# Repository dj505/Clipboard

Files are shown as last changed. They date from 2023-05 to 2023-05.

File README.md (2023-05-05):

# Clipboard
A macropad made to make copy/paste easier  
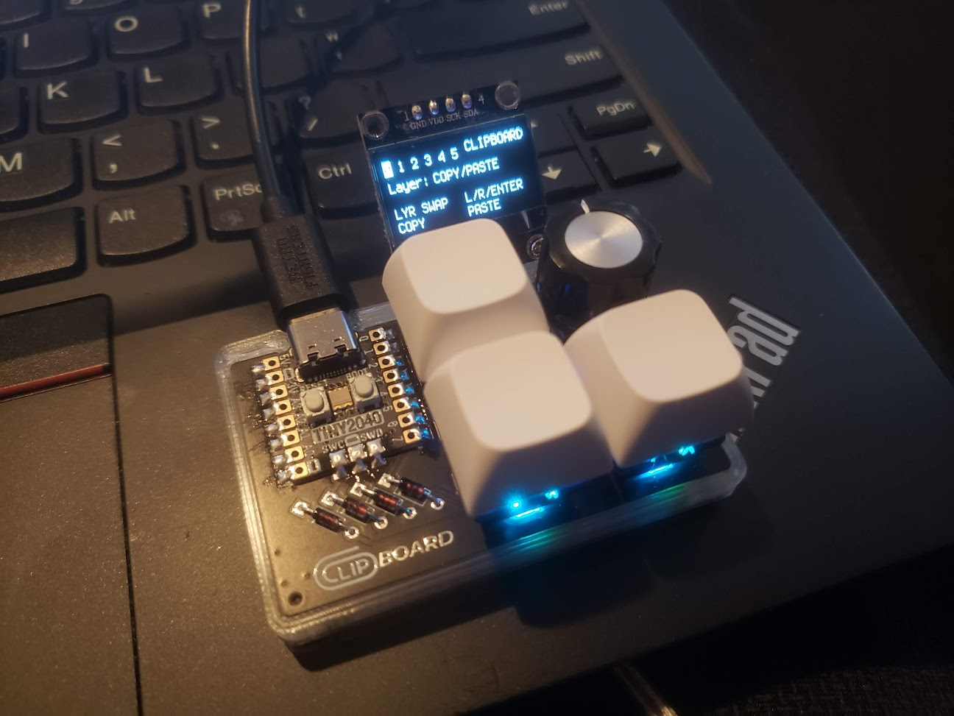
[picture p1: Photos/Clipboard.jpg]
Fully assembled Clipboard Clipboard


## Isn't this basically just a small macropad?
Yes! There's no reason you have to use this exclusively for copy/pasting, or other common shortcuts. You can do whatever you want with it, really. I was comissioned to design this by a friend who does a lot of copy/pasting at work. As he would like to save himself from a perpetually sore wrist, it was designed to the specifications he provided, right down to the specific intended use case. Since it's meant to be used for copying and pasting in an office-like environment, "Clipboard" just so happened to be a good play on words. (Shoutouts to clue for pointing that out!)

## Ok but what about the components?? The Tiny2040 is like $15 alone!
Short answer: Because I already have the parts lol

Long answer: To keep costs down, the deisgn was made to use parts we (myself and the friend who commissioned this board) already own. We both have a spare Tiny2040, I have hundreds of 1N4148 diodes from making keyboards, and I also have tons of leftover Kailh sockets and SK6812MINI-Es from the initial run of the [PicoLX](https://github.com/dj505/PicoLX).

## Update: [RP2040-Zero branch available here!](https://github.com/dj505/clipboard/tree/rp2040-zero)
The RP2040 Zero is significantly cheaper and has a near-identical pinout. Some pins remain unused but you can solder straight to the pins if you want to add any extra peripherals.

# Bill of Materials

| Part | Package | Qty |
|---|---|-----|
| 100nF Capacitor  | 0805 | 3 |
| 1N4148 Diode | DO-35 | 4 |
| SK6812MINI-E | MINI-E | 3 |
| Keyboard Switch  | MX-style | 3 |
| Rotary Encoder | PEC12R-4215F-S0024| 1 |
| Pimoroni Tiny2040| N/A | 1 |
| SN74LV1T34DBV | SOT-23-5 | 1 |

# Firmware
This board was developed using [KMK Firmware](https://github.com/KMKfw/kmk_firmware). Instructions for setting up KMK on your board can be found in the [Getting Started](https://github.com/KMKfw/kmk_firmware/blob/master/docs/en/Getting_Started.md) docs.

After KMK itself is set up, delete the existing `code.py` or `main.py` on the CIRCUITPY drive, and copy the `code.py` file in this repository's "keymap" directory to the root of the drive.

You're done!

## Notes on the firmware
- By default, it does a lot. Maybe too much. *Probably* too much, actually. Please feel free to edit it down for your own use case! The [KMK docs](http://kmkfw.io/docs/) are your friend.
- The OLED code used here is currently undocumented. It's fully reworked from example code I found on a GitHub issue thread that I can't seem to find again. It should be straightforward enough to understand, though!

## Required CircuitPython libraries
CircuitPython libraries can be found [here.](https://circuitpython.org/libraries)  
This project will require the following libraries from the "lib" folder of the library bundle:
* neopixel.mpy
* adafruit_displayio_ssd1306.mpy (required for OLED)
* adafruit_display_text (required for OLED)  
Copy these files and folders into the "lib" folder on your CIRCUITPY drive.

## Connecting an OLED display
Clipboard is made with an I2C 128x64 SSD1306 OLED display in mind. If you have a different display with a different resolution, you will have to edit `code.py` accordingly. The underside of the board has the appropriate pins marked, with **SDA on GP26** and **SCL on GP27**. The VCC (or VDD (or 3.3V)) pin on the OLED should be wired to the +3V3 pin on the Clipboard.

# Credits
* [Tiny2040 Symbol & Footprint](https://github.com/chinatsu/tiny2040) by [chinatsu](https://github.com/chinatsu) - Licensed under Creative Commons Attribution-ShareAlike 3.0 Unported. License can be found in `rp2040` directory. The following changes were made to the pcbnew footprint for this project:
    * "U1" and "Tiny2040" text on silkscreen layer have been moved
    * Rectangular pads were added to the front copper layer to allow for surface mounting
    * Silkscreen outline was changed so as to not overlap with the rectangular pads
* [marbastlib](https://github.com/ebastler/marbastlib) by [ebastler](https://github.com/ebastler) - Licensed under the CERN Open Hardware Licence Version 2 - Permissive.
* [MX_V2](https://github.com/ai03-2725/MX_V2) and [MX_Alps_Hybrid](https://github.com/ai03-2725/MX_Alps_Hybrid) by [ai03](https://github.com/ai03-2725) - Both licensed under the MIT License.

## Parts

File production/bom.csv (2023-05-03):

Designator | Footprint | Quantity | Value | LCSC Part #
C1, C2, C3 | 0805 | 3 | 100nF | C1525
D1, D2, D3, D4 | D_DO-35_SOD27_P7.62mm_Horizontal | 4 | 1N4148
J1 | PinHeader_1x08_P2.54mm_Vertical | 1 | Conn_01x08
LED1, LED2, LED3 | LED_MX_6028R | 3 | SK6812MINI-E
MX1, MX2, MX3 | MX-Hotswap-1U | 3 | MX-NoLED
SW1 | RotaryEncoder_Bourns_Vertical_PEC12R-3xxxF-Sxxxx | 1 | PEC12R-4215F-S0024
U1 | tiny2040 | 1 | tiny2040
U2 | SOT-23-5 | 1 | SN74LV1T34DBV | C100024

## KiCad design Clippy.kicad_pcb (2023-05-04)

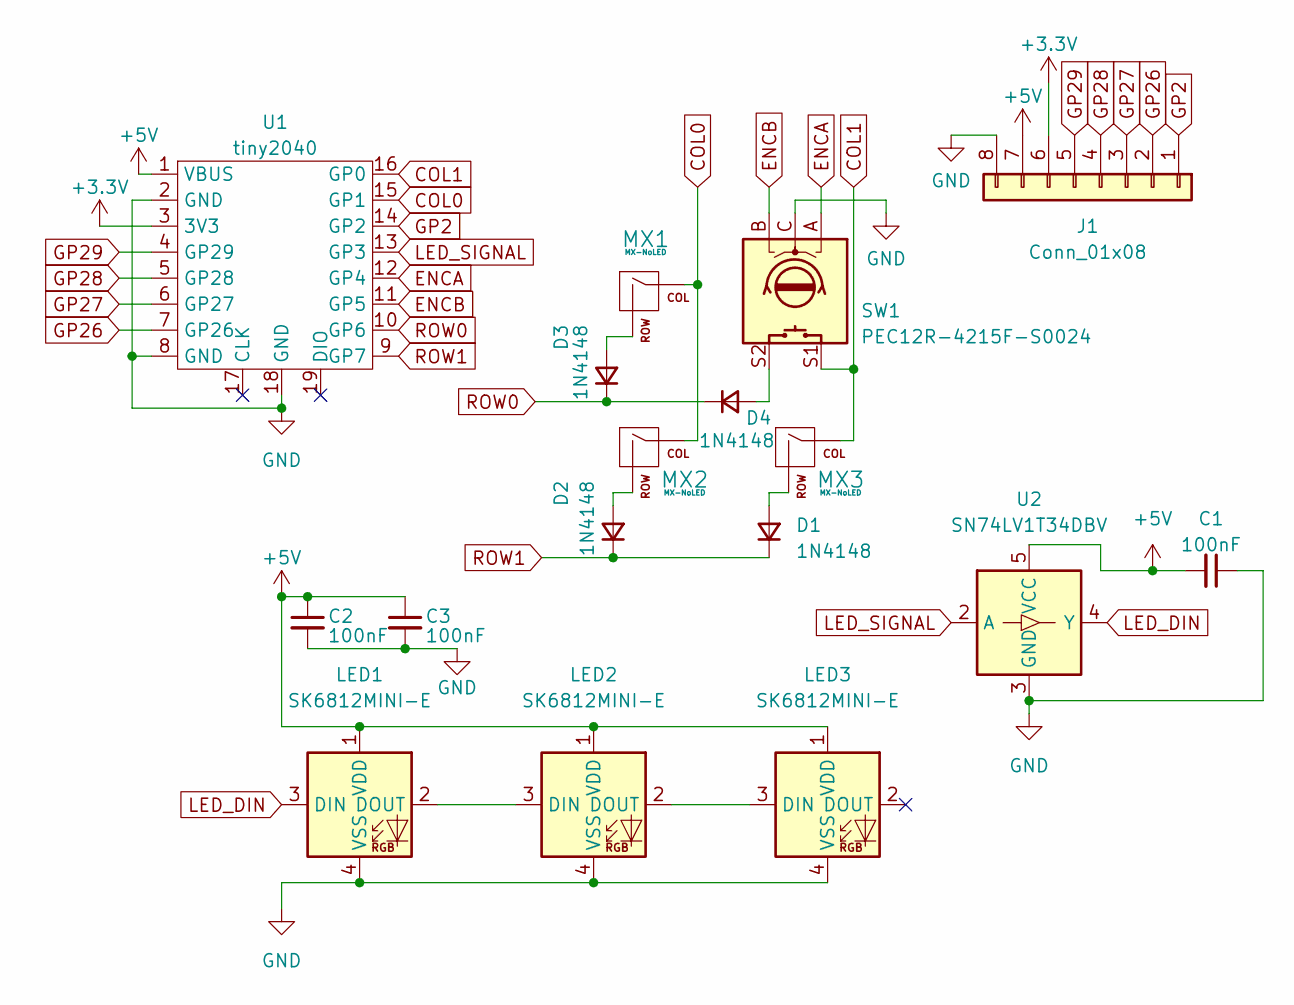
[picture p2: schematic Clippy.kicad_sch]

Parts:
C1, C2, C3: 100nF; C_0805_2012Metric_Pad1.18x1.45mm_HandSolder; LCSC C1525
D1, D2, D3, D4: 1N4148; D_DO-35_SOD27_P7.62mm_Horizontal
J1: Conn_01x08; PinHeader_1x08_P2.54mm_Vertical
LED1, LED2, LED3: SK6812MINI-E; LED_MX_6028R
MX1, MX2, MX3: MX-NoLED; MX-Hotswap-1U
SW1: PEC12R-4215F-S0024; RotaryEncoder_Bourns_Vertical_PEC12R-3xxxF-Sxxxx
U1: tiny2040
U2: SN74LV1T34DBV; SOT-23-5; LCSC C100024

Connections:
+3.3V: J1.6, U1.3 (3V3)
+5V: C1.2, C2.1, C3.1, J1.7, LED1.1 (VDD), LED2.1 (VDD), LED3.1 (VDD), U1.1 (VBUS), U2.5 (VCC)
COL0: MX1.1 (COL), MX2.1 (COL), U1.15 (GP1)
COL1: MX3.1 (COL), SW1.S1, U1.16 (GP0)
ENC0: SW1.A, U1.12 (GP4)
ENC1: SW1.B, U1.11 (GP5)
GND: C1.1, C2.2, C3.2, J1.8, LED1.4 (VSS), LED2.4 (VSS), LED3.4 (VSS), SW1.C, U1.2 (GND), U1.8 (GND), U1.18 (GND), U2.3 (GND)
GP2: J1.1, U1.14 (GP2)
GP26: J1.2, U1.7 (GP26)
GP27: J1.3, U1.6 (GP27)
GP28: J1.4, U1.5 (GP28)
GP29: J1.5, U1.4 (GP29)
LED_DIN: LED1.3 (DIN), U2.4 (Y)
LED_SIGNAL: U1.13 (GP3), U2.2 (A)
unnamed: D1.2 (A), MX3.2 (ROW)
unnamed: D2.2 (A), MX2.2 (ROW)
unnamed: D3.2 (A), MX1.2 (ROW)
unnamed: D4.2 (A), SW1.S2
unnamed: LED1.2 (DOUT), LED2.3 (DIN)
unnamed: LED2.2 (DOUT), LED3.3 (DIN)
ROW0: D3.1 (K), D4.1 (K), U1.10 (GP6)
ROW1: D1.1 (K), D2.1 (K), U1.9 (GP7)

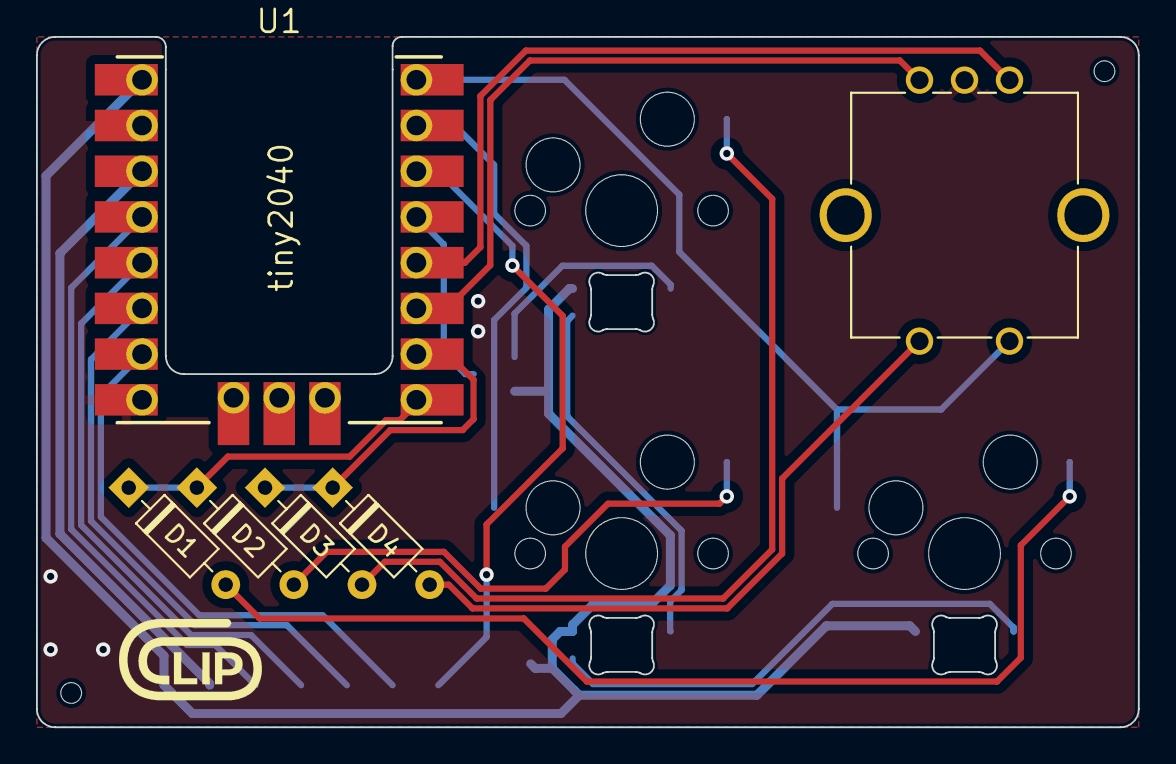
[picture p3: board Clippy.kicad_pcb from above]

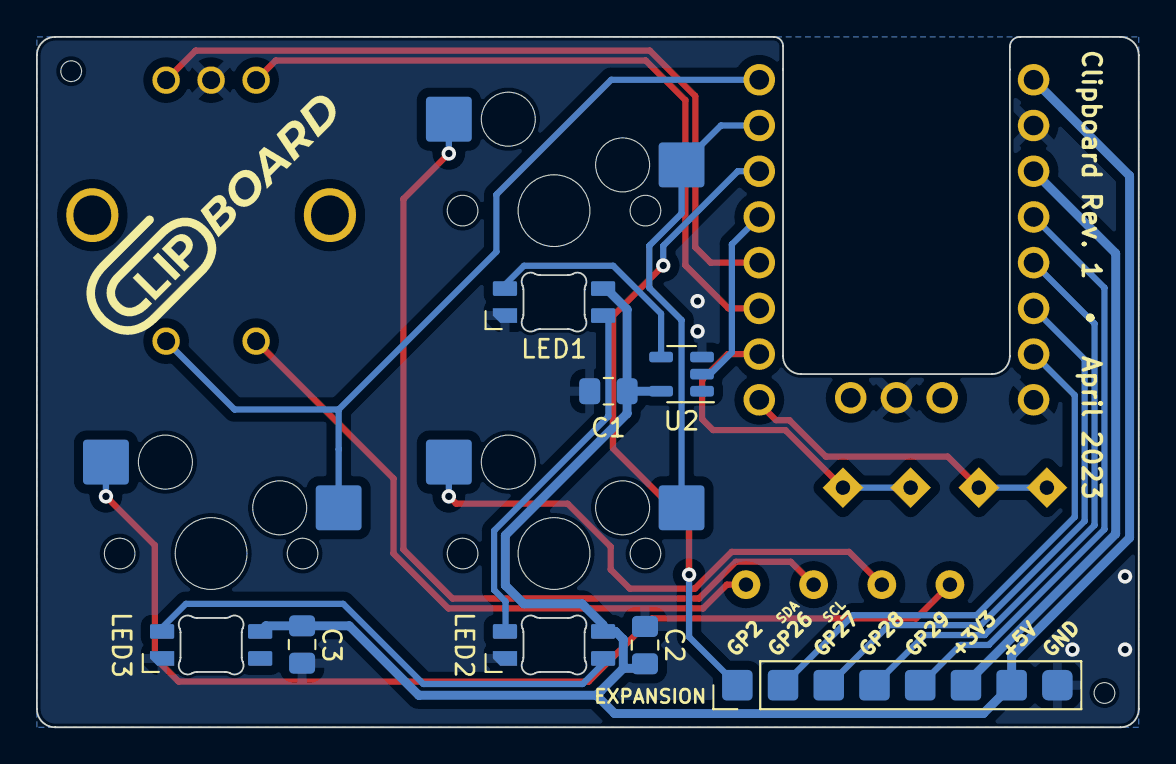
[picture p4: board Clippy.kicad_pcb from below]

Board: 2 copper layers, 61.2 x 38.4 mm, 17 parts (8 on the bottom side), 22 nets.

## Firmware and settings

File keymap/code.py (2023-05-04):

import board
import busio

from kmk.kmk_keyboard import KMKKeyboard
from kmk.keys import KC
from kmk.handlers.sequences import simple_key_sequence
from kmk.scanners import DiodeOrientation
from kmk.modules.layers import Layers
from kmk.modules.tapdance import TapDance
from kmk.modules.encoder import EncoderHandler
from kmk.modules.power import Power
from kmk.extensions.media_keys import MediaKeys
from kmk.extensions.RGB import RGB, AnimationModes
from kmk.extensions.LED import LED
from kmk.extensions.lock_status import LockStatus
from kmk.extensions.oled import (
    Oled,
    TextEntry,
    ImageEntry
)

keyboard = KMKKeyboard()

# Custom "Keys"
PAINT = simple_key_sequence(
    (
        KC.LGUI(KC.R),
        KC.MACRO_SLEEP_MS(500),
        KC.M,
        KC.S,
        KC.P,
        KC.A,
        KC.I,
        KC.N,
        KC.T,
        KC.ENTER
    )
)
TASKMGR = KC.LCTRL(KC.LSHIFT(KC.ESC))
LOCK = KC.LGUI(KC.L)

tapdance = TapDance()
tapdance.tap_time = 250
keyboard.modules.append(tapdance)

power = Power()
keyboard.modules.append(power)

i2c_bus = busio.I2C(board.GP27, board.GP26)

oled_ext = Oled(
    entries=[
        TextEntry(text='CLIPBOARD', x=128, y=0, x_anchor='R'),
        TextEntry(text='Layer: ', x=0, y=32, y_anchor='B'),
        TextEntry(text='COPY/PASTE', x=40, y=32, y_anchor='B', layer=0),
        TextEntry(text='UNDO/REDO', x=40, y=32, y_anchor='B', layer=1),
        TextEntry(text='SCREENSHOT', x=40, y=32, y_anchor='B', layer=2),
        TextEntry(text='MISC SYSTEM', x=40, y=32, y_anchor='B', layer=3),
        TextEntry(text='MEDIA', x=40, y=32, y_anchor='B', layer=4),
        TextEntry(text='RGB', x=40, y=32, y_anchor='B', layer=5),
        TextEntry(text='SETTINGS', x=40, y=32, y_anchor='B', layer=6),
        TextEntry(text='0123456', x=0, y=4),
        TextEntry(text='0', x=0, y=4, inverted=True, layer=0),
        TextEntry(text='1', x=6, y=4, inverted=True, layer=1),
        TextEntry(text='2', x=12, y=4, inverted=True, layer=2),
        TextEntry(text='3', x=18, y=4, inverted=True, layer=3),
        TextEntry(text='4', x=24, y=4, inverted=True, layer=4),
        TextEntry(text='5', x=30, y=4, inverted=True, layer=5),
        TextEntry(text='6', x=36, y=4, inverted=True, layer=6),

        # Rotary encoder labels
        TextEntry(text='L/R', x=64, y=42, layer=0),
        TextEntry(text='VOLUME', x=64, y=42, layer=1),
        TextEntry(text='ZOOM', x=64, y=42, layer=2),
        TextEntry(text='PNT ZOOM', x=64, y=42, layer=3),
        TextEntry(text='VOLUME', x=64, y=42, layer=4),
        TextEntry(text='RGB HUE', x=64, y=42, layer=5),
        TextEntry(text='UNUSED', x=64, y=42, layer=6),

        # Key labels
        TextEntry(text='SELECT', x=0, y=42, layer=0),
        TextEntry(text='COPY', x=0, y=54, layer=0),
        TextEntry(text='PASTE', x=64, y=54, layer=0),
        TextEntry(text='MUTE', x=0, y=42, layer=1),
        TextEntry(text='UNDO', x=0, y=54, layer=1),
        TextEntry(text='REDO', x=64, y=54, layer=1),
        TextEntry(text='RST ZOOM', x=0, y=42, layer=2),
        TextEntry(text='ALT+PRTSC', x=0, y=54, layer=2),
        TextEntry(text='SNIP TOOL', x=64, y=54, layer=2),
        TextEntry(text='PAINT', x=0, y=42, layer=3),
        TextEntry(text='TASK MNGR', x=0, y=54, layer=3),
        TextEntry(text='LOCK SCRN', x=64, y=54, layer=3),
        TextEntry(text='PLAY/PAUSE', x=0, y=42, layer=4),
        TextEntry(text='PREV SONG', x=0, y=54, layer=4),
        TextEntry(text='NEXT SONG', x=64, y=54, layer=4),
        TextEntry(text='RGB TGL', x=0, y=42, layer=5),
        TextEntry(text='SPD-', x=0, y=54, layer=5),
        TextEntry(text='SPD+', x=64, y=54, layer=5),
        TextEntry(text='DEBUG TGL', x=0, y=42, layer=6),
        TextEntry(text='RESET', x=0, y=54, layer=6),
        TextEntry(text='RELOAD', x=64, y=54, layer=6),
    ],
    i2c=i2c_bus,
    device_address=0x3C,
    width=128,
    height=64,
    flip=False,
    flip_left=False,
    flip_right=True,
    dim_time=10,
    dim_target=0.1,
    off_time=120,
    powersave_dim_time=5,
    powersave_dim_target=0.1,
    powersave_off_time=15,
    brightness=1,
    brightness_step=0.1,
)
keyboard.extensions.append(oled_ext)

leds = LED(led_pin=[board.LED_R, board.LED_G, board.LED_B])
# Num lock = red
# Caps lock = green
# Scroll lock = blue

class LEDLockStatus(LockStatus):
    def set_lock_leds(self):
        if not self.get_num_lock():
            leds.set_brightness(100, leds=[0])
        else:
            leds.set_brightness(0, leds=[0])

        if not self.get_caps_lock():
            leds.set_brightness(100, leds=[1])
        else:
            leds.set_brightness(0, leds=[1])

        if not self.get_scroll_lock():
            leds.set_brightness(100, leds=[2])
        else:
            leds.set_brightness(0, leds=[2])

    def after_hid_send(self, sandbox):
        super().after_hid_send(sandbox)
        if self.report_updated:
            self.set_lock_leds()

keyboard.extensions.append(leds)
keyboard.extensions.append(LEDLockStatus())

keyboard.col_pins = (board.GP1, board.GP0)
keyboard.row_pins = (board.GP6, board.GP7)
keyboard.diode_orientation = DiodeOrientation.COL2ROW

layers = Layers()
keyboard.modules.append(layers)

media_keys = MediaKeys()
keyboard.extensions.append(media_keys)

frontglow = RGB(
    pixel_pin=board.GP3,
    num_pixels=3,
    val_limit=100,
    val_default=25,
    animation_mode=AnimationModes.RAINBOW,
)
keyboard.extensions.append(frontglow)

keyboard.keymap = [
    [   # Layer 1 - Copy/Paste
        KC.TD(KC.LSHIFT, KC.LCTRL(KC.A)), KC.TD(KC.TO(1), KC.TO(6)), # Shift/Ctrl+A, Toggle layer 2,
        KC.LCTRL(KC.C),                   KC.LCTRL(KC.V)             # Ctrl+C, Ctrl+V
    ],
    [
        # Layer 2 - Undo/Redo
        KC.MUTE,                          KC.TD(KC.TO(2), KC.TO(0)), # Mute, Toggle layer 3,
        KC.LCTRL(KC.Z),                   KC.LCTRL(KC.Y)             # Ctrl+Z, Ctrl+Y
    ],
    [
        # Layer 3 - Screenshots
        KC.LCTRL(KC.N0),                  KC.TD(KC.TO(3), KC.TO(1)), # CTRL+0, Toggle layer 4,
        KC.LALT(KC.PSCREEN),              KC.LGUI(KC.LSHIFT(KC.S))   # PrtSc, Alt+PrtSc
    ],
    [
        # Layer 4 - Misc System
        PAINT,                            KC.TD(KC.TO(4), KC.TO(2)), # MS Paint, Toggle layer 5,
        TASKMGR,                          LOCK                       # task manager, Win+L
    ],
    [
        # Layer 5 - Media Controls
        KC.MPLY,                          KC.TD(KC.TO(5), KC.TO(3)), # Mute, Toggle layer 6,
        KC.MPRV,                          KC.MNXT                    # Next song, previous song
    ],
    [   # Layer 6 - RGB Settings
        KC.RGB_TOG,                       KC.TD(KC.TO(6), KC.TO(4)), # toggle RGB, Toggle layer 1,
        KC.RGB_AND,                       KC.RGB_ANI                 # decrease animation speed, increase animation speed
    ],
    [   # Layer 7 - KMK Settings
        KC.DEBUG,                         KC.TD(KC.TO(0), KC.TO(5)), # Toggle power saving, toggle RGB,
        KC.RESET,                         KC.RELOAD                  # reset, reload
    ]

]

encoder_handler = EncoderHandler()
encoder_handler.divisor = 4
encoder_handler.pins = ((board.GP4, board.GP5, None),)

encoder_handler.map = [
    [( KC.LEFT,             KC.RIGHT)],            # Layer 1 (Left, right arrows)
    [( KC.VOLD,             KC.VOLU)],             # Layer 2 (Also volume down, volume up)
    [( KC.LCTRL(KC.MINUS),  KC.LCTRL(KC.EQUAL) )], # Layer 3 (Ctrl +, Ctrl -)
    [( KC.LCTRL(KC.PGDOWN), KC.LCTRL(KC.PGUP) )],  # Layer 4 (Paint zoom in, zoom out)
    [( KC.VOLD,             KC.VOLU)],             # Layer 5 (Once again, volume down, volume up)
    [( KC.RGB_HUD,          KC.RGB_HUI )]          # Layer 6 (RGB hue decrease, increase)
]

keyboard.modules.append(encoder_handler)

if __name__ == '__main__':
    keyboard.go()

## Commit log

2023-04-25 Final touches?
    [Clippy.kicad_pcb, Clippy.kicad_sch]
2023-04-25 Add tooling holes
2023-04-25 oops. Actually add tooling holes
    [Clippy.kicad_pcb]
2023-04-25 Fix DRC errors to a reasonable extent
    [Clippy.kicad_pcb]
2023-04-25 finishing touches
    [Clippy.kicad_pcb, bom.csv, designators.csv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]
2023-04-26 finishing touches 2 electric boogaloo
    [Clippy.kicad_pcb, Clippy.kicad_sch, bom.csv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]
2023-04-27 oops rows were swapped in the schematic
    [Clippy.kicad_pcb, Clippy.kicad_sch]
2023-04-28 Edit schematic labels, initial keymap
    [Clippy.kicad_pcb, Clippy.kicad_sch]
2023-05-03 Version 1.0 release commit
    [bom.csv]
2023-05-04 More firmware things, update readme
    [Clippy.kicad_pcb]
